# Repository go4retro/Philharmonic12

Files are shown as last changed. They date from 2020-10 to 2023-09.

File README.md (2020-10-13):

# Philharmonic 12 

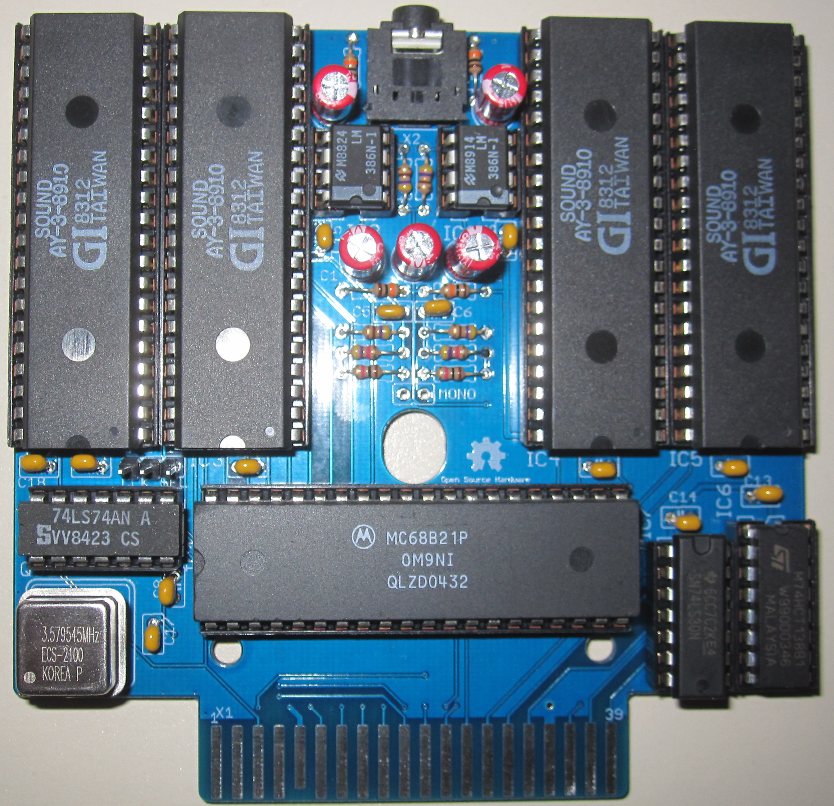
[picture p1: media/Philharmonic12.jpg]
Populated PCB


A 12 Voice Hardware Music Synthesizer for the TANDY Color Computer and Dragon

This cartridge reproduces the functionality of the Speech Systems "Symphony 12" cartridge.

NOTE:  As of 2018-12-24, this design has not been built and tested.  Caveat Emptor!

## Reproduction Changes
Although the schematic on page 27 of the Owner's Manual was followed to implement this reproduction, the schematic was incomplete, and so a few changes were made to minimize parts count and fill in the gaps.

The decoding of the MC6821 /CS2 line was defined as "pin 15 74ls138 $ff60", which implied that $ff60 would represent a low level on pin 15 of the IC (a 3-8 decoder), which is value "0".  That meant input lines A,B, and C must be low levels.  Since address lines 0 and 1 select the specific MC6821 register, it is assumed address lines 2,3, and 4 are sent to inputs A, B, and C.  Furthermore, since the unit decodes to $ff60, which is above the /SCS space, a full address decode must be done.  A 74LS30 8 input NAND gate was used to decode an $ffxx access, and that output was used to gate the '138.  Address lines 7, 6, and 5 were still not decoded, but must be set to 011.  Thus, A7 was sent to a negative select line on the '138, while A5 and A6 were sent to active high select lines on the MC6821 (which are tied to +5V on the original schematic).  THis change should not affect functionality.

Another difference lies in the clock signal for the sound ICs.  The original schematic ties the sound clock to 6809 E clock, which provides a stable .895MHz signal on all computers except for the Color Computer 3.  On the CoCo 3, the E clock can be set to .895MHz or 1.79MHz.  This will affect the pitch of the audio considerably.  Thus, a stable .895MHz oscillator was included on the PCB design, though a jumper cna still be used to select the E clock if desired.

Finally, the AY-3-8912 ICs used in the original design are harder to find than the larger cousin, the AY-3-8910.  Thus, this design used the larger and cheaper ICs.

## License
Copyright (C) 2018  RETRO Innovations

These files are free designs; you can redistribute them and/or modify
them under the terms of the Creative Commons Attribution-ShareAlike 
4.0 International License.

You should have received a copy of the license along with this
work. If not, see <http://creativecommons.org/licenses/by-sa/4.0/>.

These files are distributed in the hope that they will be useful,
but WITHOUT ANY WARRANTY; without even the implied warranty of
MERCHANTABILITY or FITNESS FOR A PARTICULAR PURPOSE.  See the
license for more details.

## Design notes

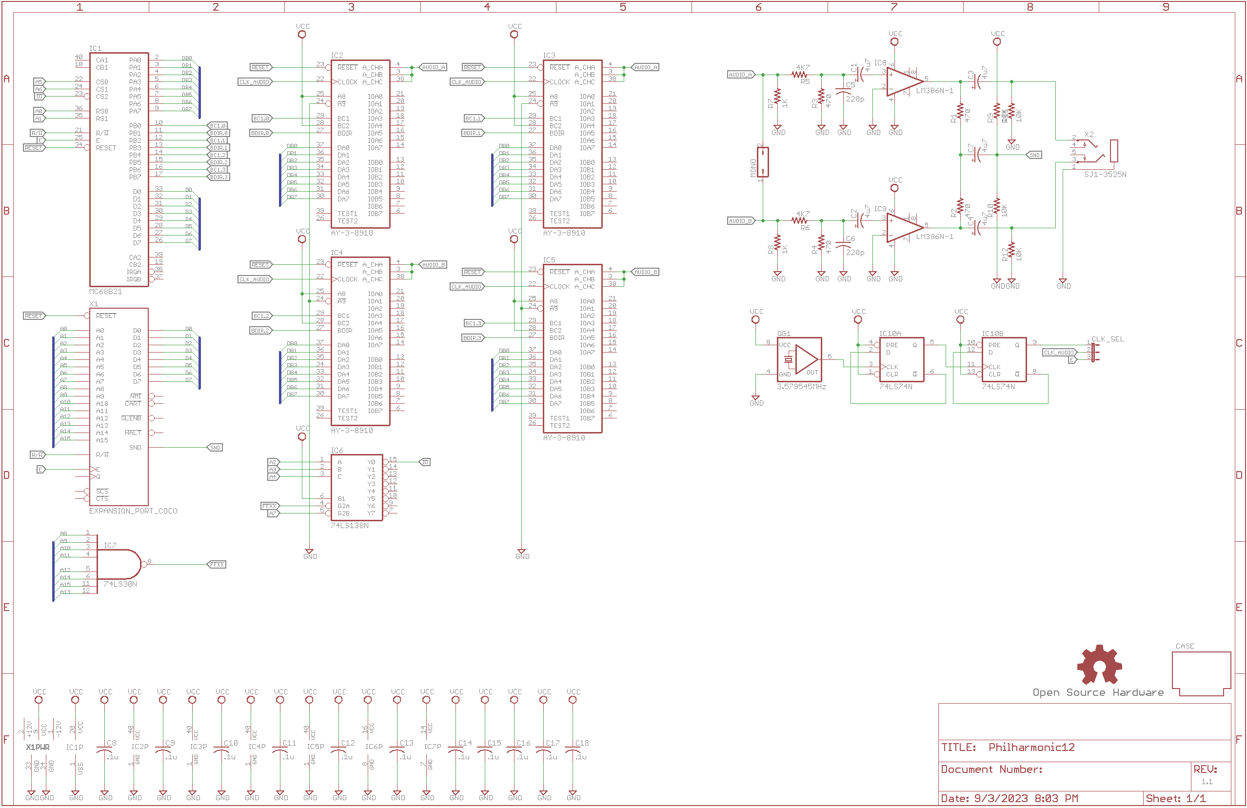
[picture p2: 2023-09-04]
pcb/Philharmonic 12 Schematic.png

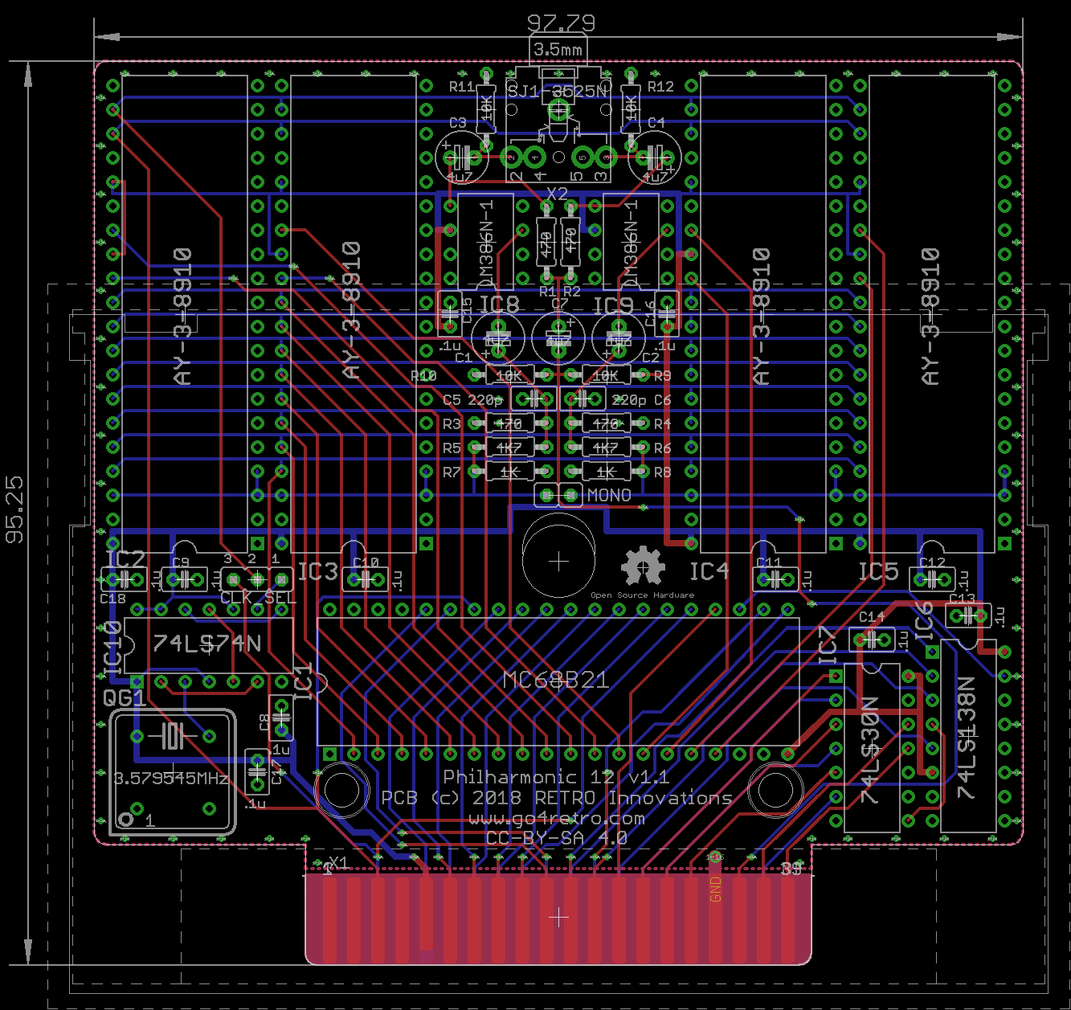
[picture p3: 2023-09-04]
pcb/Philharmonic 12 PCB.png

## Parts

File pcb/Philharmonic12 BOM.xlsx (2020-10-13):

Part | Quantity | Value | Description | Note: | Link
C1,C2,C3,C4,C7 | 5 | 4u7 | POLARIZED CAPACITOR, American symbol | 10V or better is fine | https://www.digikey.com/en/products/detail/w-rth-elektronik/860010472001/5728580
C5,C6 | 2 | 220p | CAPACITOR, American symbol | 10V or better is fine | https://www.digikey.com/en/products/detail/vishay-beyschlag-draloric-bc-components/K221J15C0GF5TL2/286639
C8,9,10,11,12,13,14,15,16,17,18 | 11 | .1u | CAPACITOR, American symbol | 10V or better is fine | https://www.digikey.com/en/products/detail/vishay-beyschlag-draloric-bc-components/K104K15X7RF5TL2/286538
CLK_SEL, MONO | 1 |  | JUMPER | break into 1 1x2 and 1 1x3 | https://www.digikey.com/en/products/detail/amphenol-icc-fci/68002-406HLF/1878494
IC1 | 1 | MC68B21 | MICROCONTROLLER/MEMORY DEVICE | Must be 'B' speed grade if used on CoCo 3 | https://www.utsource.net/itm/p/135503.html
IC2,3,4,5 | 4 | AY-3-8910 | Programmable sound generator | YM-2149 can be used as well | https://www.utsource.net/itm/p/446115.html
IC6 | 1 | 74LS138N | 3-line to 8-line DECODER/DEMULTIPLEXER | must be at least as fast as LS | https://www.digikey.com/en/products/detail/texas-instruments/SN74LS138N/277285
IC7 | 1 | 74LS30N | 8-input NAND gate | must be at least as fast as LS | https://www.digikey.com/en/products/detail/texas-instruments/SN74LS30N/377726
IC8,9 | 2 | LM386N-1 | Low Voltage Audio Power Amplifier |  | https://www.digikey.com/en/products/detail/texas-instruments/LM386N-1-NOPB/6284
IC10 | 1 | 74LS74N | Dual D type positive edge triggered FLIP FLOP, preset and clear | hct and other families will work | https://www.digikey.com/en/products/detail/texas-instruments/SN74LS74AN/277314
 | 2 |  | Shorting Blocks | nothing special | https://www.digikey.com/en/products/detail/kycon-inc/SX1100-A/9990205
QG1 | 1 | 3.579545MHz | CRYSTAL RESONATOR |  | https://www.digikey.com/en/products/detail/ecs-inc/ECS-2100A-035/31990
R1,2,3,4 | 4 | 470 | RESISTOR, American symbol | Any 1/8W | https://www.digikey.com/en/products/detail/stackpole-electronics-inc/CF18JT470R/2022734
R5,6 | 2 | 4K7 | RESISTOR, American symbol | Any 1/8W | https://www.digikey.com/en/products/detail/stackpole-electronics-inc/CF18JT4K70/2022758
R7,8 | 2 | 1K | RESISTOR, American symbol | Any 1/8W | https://www.digikey.com/en/products/detail/stackpole-electronics-inc/CF18JT1K00/1741612
R9,10,11,12 | 4 | 10K | RESISTOR, American symbol | Any 1/8W | https://www.digikey.com/en/products/detail/stackpole-electronics-inc/CF18JT10K0/1741566
X2 | 1 | SJ1-3523N | 3.5mm Stereo Jack | can also use SJ1-3524 or 3525 | https://www.digikey.com/en/products/detail/cui-devices/SJ1-3523N/738689

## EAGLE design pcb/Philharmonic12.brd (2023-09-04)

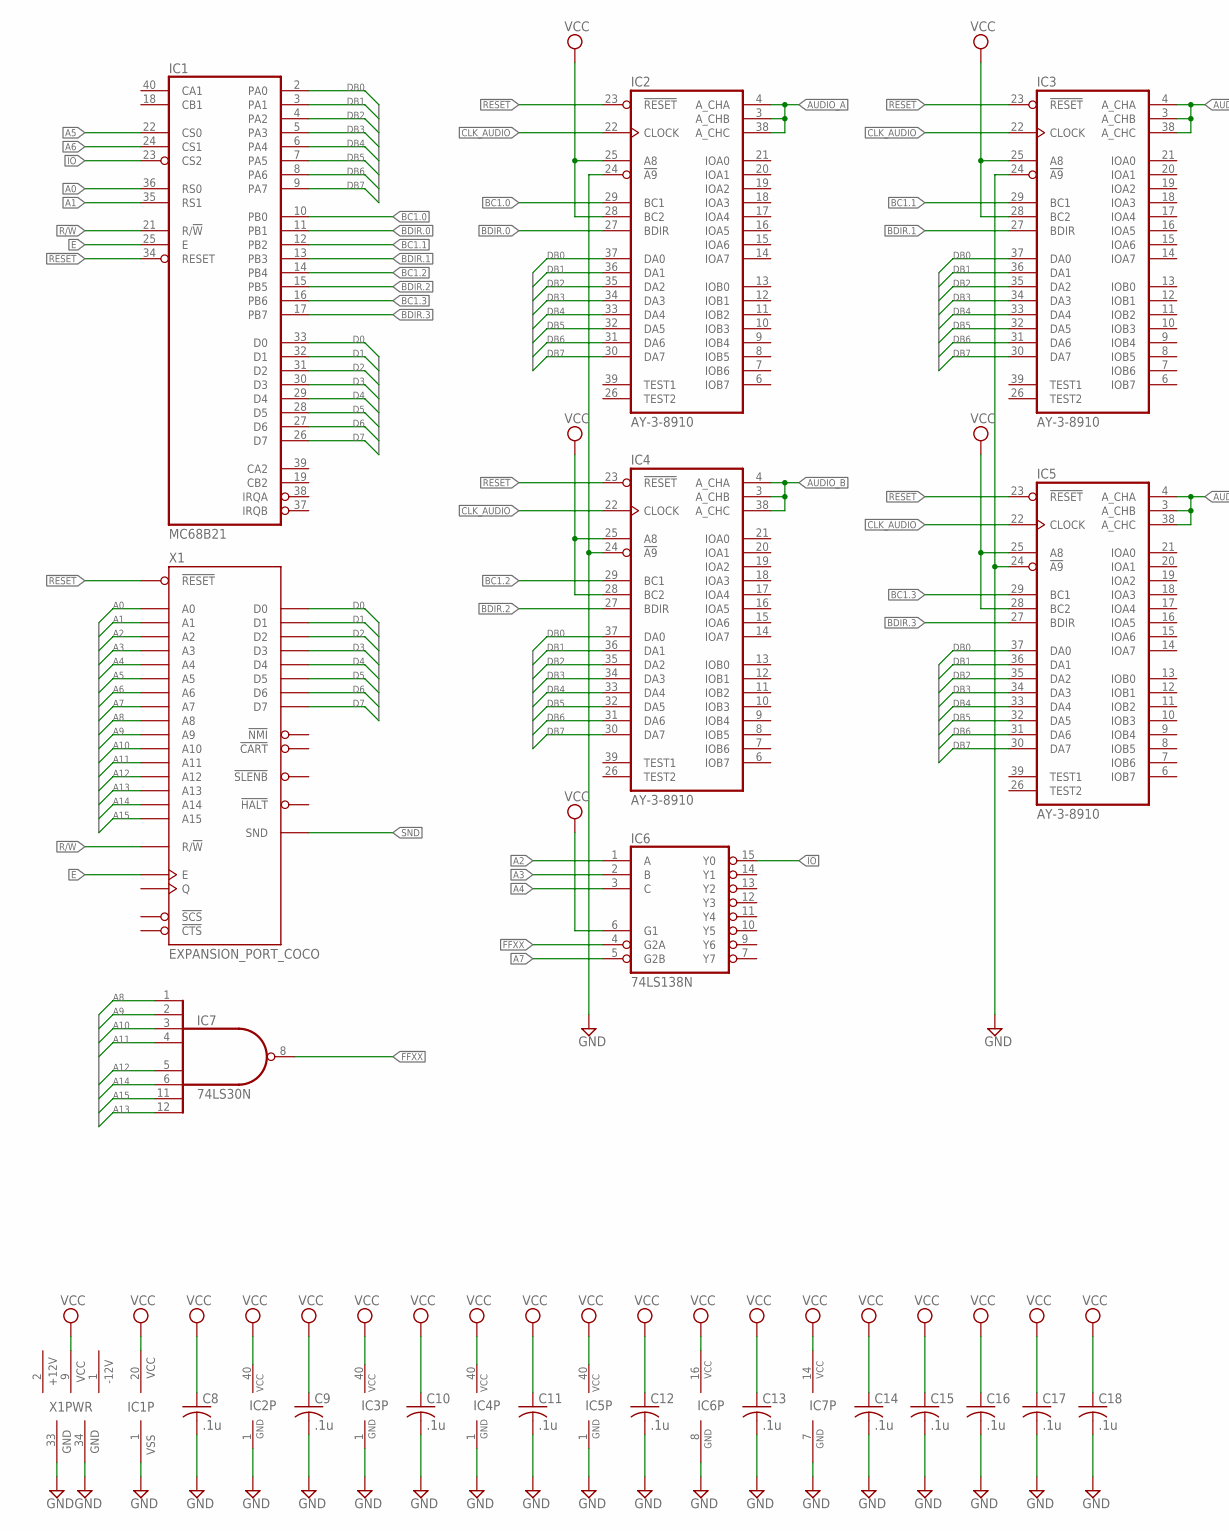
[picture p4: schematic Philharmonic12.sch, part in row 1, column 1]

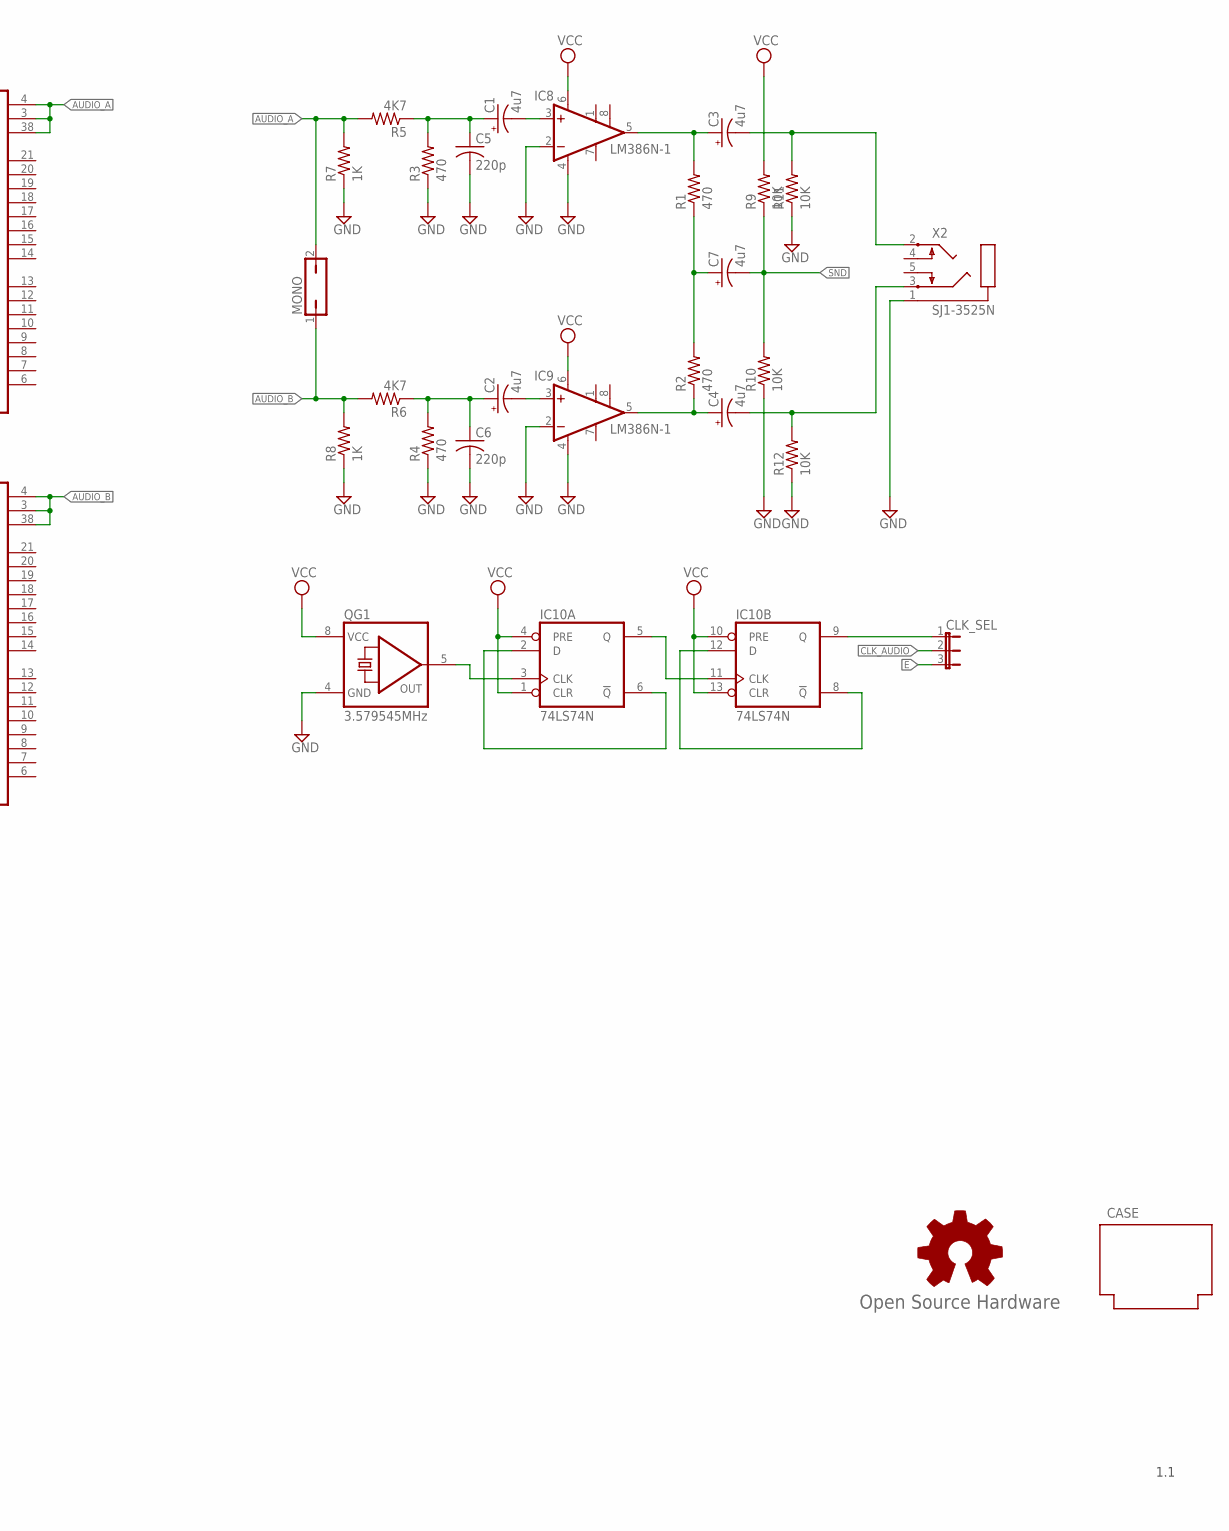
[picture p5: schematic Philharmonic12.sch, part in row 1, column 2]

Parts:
C1, C2, C3, C4, C7: 4u7; E2,5-6
C5, C6: 220p; C025-025X050
C8, C9, C10, C11, C12, C13, C14, C15, C16, C17, C18: .1u; C025-025X050
CASE: PROGRAM_PAK
CLK_SEL: JP2E; JP2
GOLD_ORB_SM1: Open Source Hardware; OSHW_5MM
IC1: MC68B21; DIL40-ROUNDPAD
IC2, IC3, IC4, IC5: AY-3-8910; DIL40-RP
IC6: 74LS138N; DIL16-RP
IC7: 74LS30N; DIL14-RP
IC8, IC9: LM386N-1; DIL08
IC10: 74LS74N; DIL14-RP
MONO: JP1Q; JP1
QG1: 3.579545MHz; DIL08S
R1, R2, R3, R4: 470; 0204/7
R5, R6: 4K7; 0204/7
R7, R8: 1K; 0204/7
R9, R10, R11, R12: 10K; 0204/7
X1: EXPANSION_PORT_COCO; MA20-2
X2: SJ1-3525N

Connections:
!FFXX: IC6.4 (G2A), IC7.8 (O)
!IO: IC1.23 (CS2), IC6.15 (Y0)
!RESET: IC1.34 (RESET), IC2.23 (!RESET), IC3.23 (!RESET), IC4.23 (!RESET), IC5.23 (!RESET), X1.5 (!RESET)
+12V: X1.2 (+12V)
-12V: X1.1 (-12V)
A0: IC1.36 (RS0), X1.19 (A0)
A1: IC1.35 (RS1), X1.20 (A1)
A2: IC6.1 (A), X1.21 (A2)
A3: IC6.2 (B), X1.22 (A3)
A4: IC6.3 (C), X1.23 (A4)
A5: IC1.22 (CS0), X1.24 (A5)
A6: IC1.24 (CS1), X1.25 (A6)
A7: IC6.5 (G2B), X1.26 (A7)
A8: IC7.1 (I0), X1.27 (A8)
A9: IC7.2 (I1), X1.28 (A9)
A10: IC7.3 (I2), X1.29 (A10)
A11: IC7.4 (I3), X1.30 (A11)
A12: IC7.5 (I4), X1.31 (A12)
A13: IC7.12 (I7), X1.37 (A13)
A14: IC7.6 (I5), X1.38 (A14)
A15: IC7.11 (I6), X1.39 (A15)
AUDIO_A: IC2.3 (A_CHB), IC2.4 (A_CHA), IC2.38 (A_CHC), IC3.3 (A_CHB), IC3.4 (A_CHA), IC3.38 (A_CHC), MONO.2, R5.2, R7.2
AUDIO_B: IC4.3 (A_CHB), IC4.4 (A_CHA), IC4.38 (A_CHC), IC5.3 (A_CHB), IC5.4 (A_CHA), IC5.38 (A_CHC), MONO.1, R6.2, R8.2
BC1.0: IC1.10 (PB0), IC2.29 (BC1)
BC1.1: IC1.12 (PB2), IC3.29 (BC1)
BC1.2: IC1.14 (PB4), IC4.29 (BC1)
BC1.3: IC1.16 (PB6), IC5.29 (BC1)
BDIR.0: IC1.11 (PB1), IC2.27 (BDIR)
BDIR.1: IC1.13 (PB3), IC3.27 (BDIR)
BDIR.2: IC1.15 (PB5), IC4.27 (BDIR)
BDIR.3: IC1.17 (PB7), IC5.27 (BDIR)
CLK: IC10.3 (CLK), QG1.5 (OUT)
CLK/2: IC10.5 (Q), IC10.11 (CLK)
CLK/4: CLK_SEL.1, IC10.9 (Q)
CLK_AUDIO: CLK_SEL.2, IC2.22 (CLOCK), IC3.22 (CLOCK), IC4.22 (CLOCK), IC5.22 (CLOCK)
D0: IC1.33 (D0), X1.10 (D0)
D1: IC1.32 (D1), X1.11 (D1)
D2: IC1.31 (D2), X1.12 (D2)
D3: IC1.30 (D3), X1.13 (D3)
D4: IC1.29 (D4), X1.14 (D4)
D5: IC1.28 (D5), X1.15 (D5)
D6: IC1.27 (D6), X1.16 (D6)
D7: IC1.26 (D7), X1.17 (D7)
DB0: IC1.2 (PA0), IC2.37 (DA0), IC3.37 (DA0), IC4.37 (DA0), IC5.37 (DA0)
DB1: IC1.3 (PA1), IC2.36 (DA1), IC3.36 (DA1), IC4.36 (DA1), IC5.36 (DA1)
DB2: IC1.4 (PA2), IC2.35 (DA2), IC3.35 (DA2), IC4.35 (DA2), IC5.35 (DA2)
DB3: IC1.5 (PA3), IC2.34 (DA3), IC3.34 (DA3), IC4.34 (DA3), IC5.34 (DA3)
DB4: IC1.6 (PA4), IC2.33 (DA4), IC3.33 (DA4), IC4.33 (DA4), IC5.33 (DA4)
DB5: IC1.7 (PA5), IC2.32 (DA5), IC3.32 (DA5), IC4.32 (DA5), IC5.32 (DA5)
DB6: IC1.8 (PA6), IC2.31 (DA6), IC3.31 (DA6), IC4.31 (DA6), IC5.31 (DA6)
DB7: IC1.9 (PA7), IC2.30 (DA7), IC3.30 (DA7), IC4.30 (DA7), IC5.30 (DA7)
E: CLK_SEL.3, IC1.25 (E), X1.6 (E)
GND: C5.2, C6.2, C8.2, C9.2, C10.2, C11.2, C12.2, C13.2, C14.2, C15.2, C16.2, C17.2, C18.2, IC1.1 (VSS), IC2.1 (GND), IC2.24 (!A9), IC3.1 (GND), IC3.24 (!A9), IC4.1 (GND), IC4.24 (!A9), IC5.1 (GND), IC5.24 (!A9), IC6.8 (GND), IC7.7 (GND), IC8.2 (-IN), IC8.4 (GND), IC9.2 (-IN), IC9.4 (GND), IC10.7 (GND), QG1.4 (GND), R3.1, R4.1, R7.1, R8.1, R10.1, R11.1, R12.1, X1.33 (GND), X1.34 (GND), X2.1
unnamed: IC10.2 (D), IC10.6 (!Q)
unnamed: C7.+, R1.1, R2.2
unnamed: C4.-, R12.2, X2.3
unnamed: C3.+, IC8.5 (OUT), R1.2
unnamed: C4.+, IC9.5 (OUT), R2.1
unnamed: C1.-, IC8.3 (+IN)
unnamed: C1.+, C5.1, R3.2, R5.1
unnamed: C2.-, IC9.3 (+IN)
unnamed: C2.+, C6.1, R4.2, R6.1
unnamed: IC10.8 (!Q), IC10.12 (D)
unnamed: C3.-, R11.2, X2.2
R/!W: IC1.21 (R/!W), X1.18 (R/!W)
SND: C7.-, R9.1, R10.2, X1.35 (SND)
VCC: C8.1, C9.1, C10.1, C11.1, C12.1, C13.1, C14.1, C15.1, C16.1, C17.1, C18.1, IC1.20 (VCC), IC2.25 (A8), IC2.28 (BC2), IC2.40 (VCC), IC3.25 (A8), IC3.28 (BC2), IC3.40 (VCC), IC4.25 (A8), IC4.28 (BC2), IC4.40 (VCC), IC5.25 (A8), IC5.28 (BC2), IC5.40 (VCC), IC6.6 (G1), IC6.16 (VCC), IC7.14 (VCC), IC8.6 (VS), IC9.6 (VS), IC10.1 (CLR), IC10.4 (PRE), IC10.10 (PRE), IC10.13 (CLR), IC10.14 (VCC), QG1.8 (VCC), R9.2, X1.9 (VCC)

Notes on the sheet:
1.1

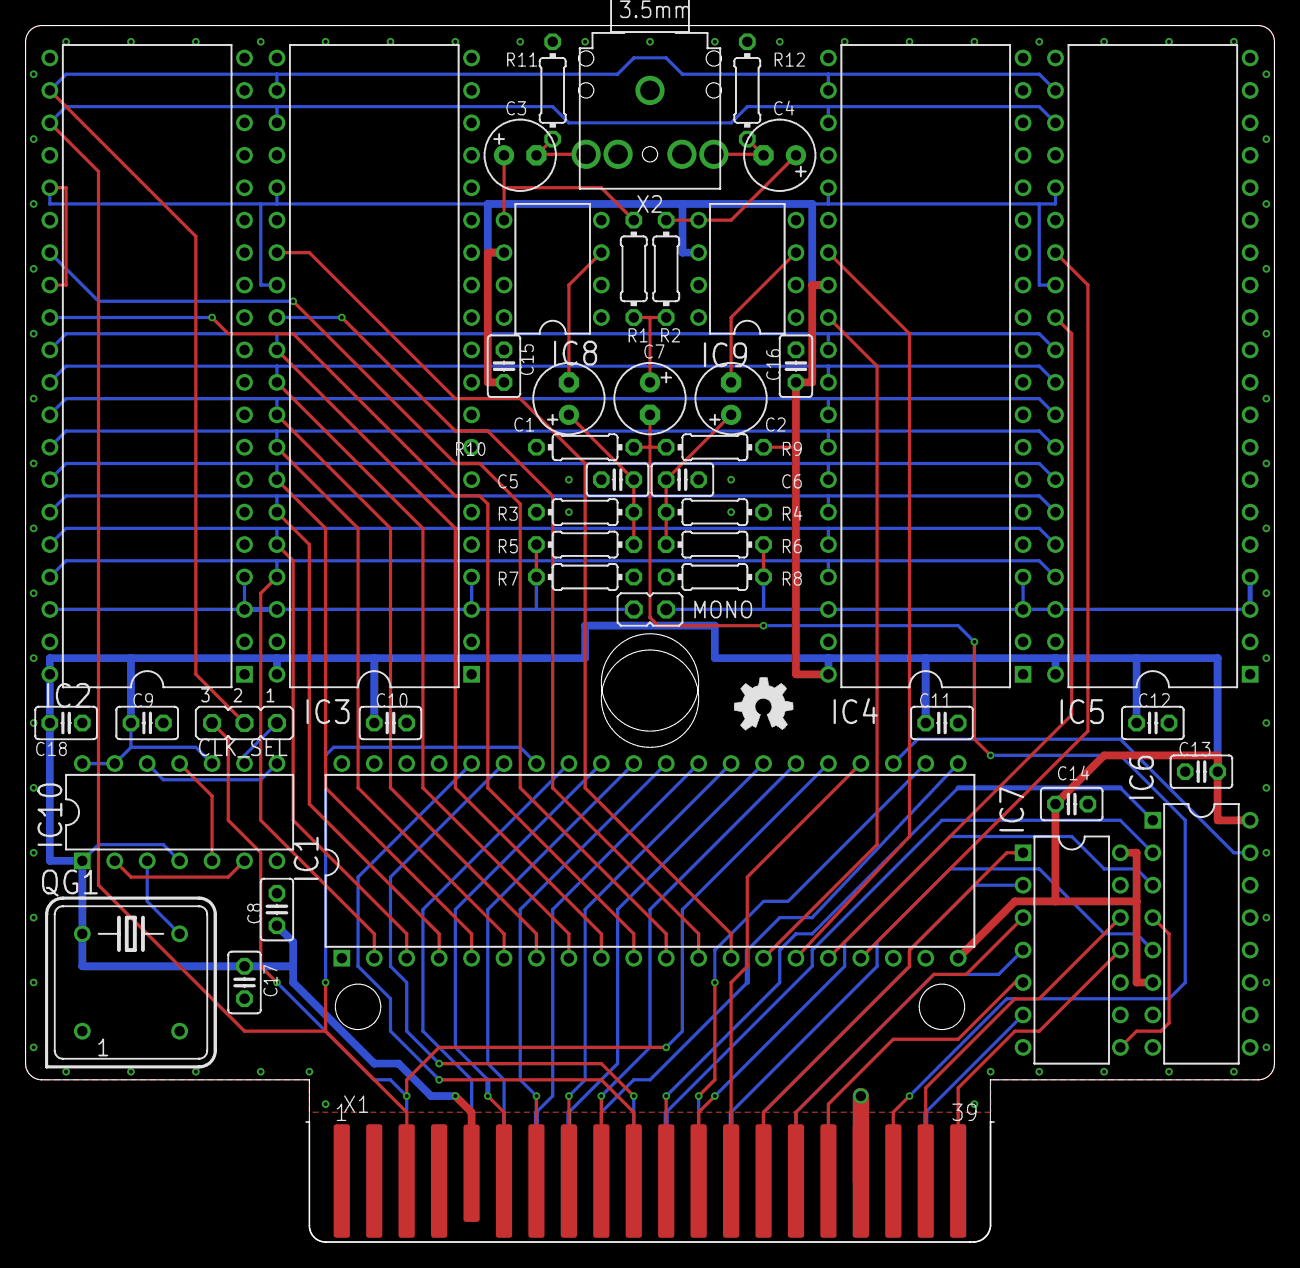
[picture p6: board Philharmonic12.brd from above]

Board: 2 copper layers, 97.8 x 95.2 mm, 47 parts (0 on the bottom side), 65 nets.

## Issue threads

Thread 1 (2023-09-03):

PCB Marking and BOM do not match for R4 and R6

hexbus, 2023-09-03:
PCB has R6 being a 470 ohm and R4 being a 4K7 resistor, but the BOM has R1,2,3,4 being 470 ohm and R5,6 being 4K7.

So, is the BOM or the PCB correct?  Thanks!

go4retro, 2023-09-04:
BOM is right, but the R4/R6 was placed wrong on the PCB.  I will update.  Check the new PCB PNG for correct labels.  Thanks for finding the error.

go4retro, 2023-09-04:
Fixed with this commit: https://github.com/go4retro/Philharmonic12/commit/c6d84ed5600dc92936110f36d66de8313380bf22

go4retro, 2023-09-04:
closing

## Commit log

2018-12-25 Can't get .895MHz oscillators, so modified to use 3.59MHz and /4 divider.
    [Philharmonic12.brd, Philharmonic12.sch]
2019-02-03 Added parts values
    [Philharmonic12.brd, Philharmonic12.sch]
2019-10-28 Minor silkscreen updates
    [Philharmonic12.brd, Philharmonic12.sch]
2020-01-11 CoCo Cart Port was slightly too narrow. Widened to make for snug fit.
    [Philharmonic12.brd, Philharmonic12.sch]
2020-04-23 Small dimension updates
    [Philharmonic12.brd, Philharmonic12.sch]
2020-10-13 Updates to schematic, Added BOM, and added sample code written by Chet Simpson
    [Philharmonic12 BOM.xlsx, Philharmonic12.brd, Philharmonic12.sch]
2020-10-13 Added populated PCB picture
2023-09-04 Fix PCB legend placement error noted in Issue #1 (hexbus reported)
    [Philharmonic12.brd, Philharmonic12.sch]

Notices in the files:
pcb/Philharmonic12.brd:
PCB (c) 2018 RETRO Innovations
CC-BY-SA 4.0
